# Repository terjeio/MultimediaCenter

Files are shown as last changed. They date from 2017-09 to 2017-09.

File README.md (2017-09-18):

# Multimedia center with DAB/FM radio

Features:

High quality (IMO) pre-amp board with I2C control of inputs and VCA based volume control.

5 line inputs, one may be fitted with an internal RIAA-preamp (phono, for moving magnet cartridges).
2 line outputs with old-style tape copy function and post listening possible.

Power amplifier on/off switching via inbuilt relay river.

KeyStone DAB/FM-module may be fitted.

Custom Raspberry PI power switch with PC-style startup/shutdown, may be controlled over I2C or from a front panel button.
Has "breakout" socket for internal USB HDD.

IR Remote Control - RC5 protocol: for input selection, volume control and UI controller navigation.

Main controller built around a Texas Instruments Tiva C MPU, custom UI library with support for KeyStone radio-module.

Raspberry PI for media playback (via Kodi), in my configuration audio is fed via HDMI to a TV and then to a DAC mounted inside the pre-amp cabinet.

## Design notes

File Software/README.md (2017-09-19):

# Power control daemon for Raspberry Pi 2 & 3

This daemon monitors and sets a pin for handling power to the Raspberry Pi "PC-style".
It is written in plain C and does direct GPIO reads/writes.

The PowerSwitch PCB/firmware handles the power relay and a on/off button & status LED.

A short button press initiates power-up or shutdown according to the current state. A long press (> 4s) when the Pi is in the running state forces a hard reset.

The solution can easily be adopted to other usage scenarioes, I have made use of it in my 3D-printer controller that runs OctoPrint.

Installation details and references can be found in the source code.

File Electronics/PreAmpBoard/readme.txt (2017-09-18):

MAYA Huracan PreAmp MK III Rev. A by

Terje Io
Io Engineering

Licensed under CERN OHL v.1.2 or later except the RIAA-circuitry which I believe is public domain.

The RIAA-circuitry was published by now defunct danish magazine High Fidelity way back in the 1980's.
I no longer have a copy of the issue(s) related to the design so I am not sure about any related copyright
but it surely is available for non-commercial use.

NOTE: Rev A has not yet been been verified as a working design.

Firmware will be released as a separate package under a different license after the design is verified.

A limited number of PCBs might or might not be made available for purchase at cost.

Files are in KiCad format.

2017-09-18

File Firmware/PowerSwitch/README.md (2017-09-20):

# PowerSwitch firmware

Firmware code is in a [separate project](https://github.com/terjeio/PowerSwitchFirmware/) since it seems to me Git does not allow cloning of subfolders in a project. Also, it is convenient to be able to import the code straight into TIs cloud based IDE for compilation and upload.

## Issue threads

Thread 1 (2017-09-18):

PA part

Claudio-Sjo, 2017-09-18:
Hi,
power amplifier is still empty.
Will you add this also?
Did you consider reusing "Superfast PA" design?

terjeio, 2017-09-18:
My current power amplifier is based on an ancient Motorola design with some hard to source components, I am not sure I want to publish that. There are many designs available on the internet so it should not be a problem finding one that can be used. When I run out of PCBs for the current design I migth try class D topology in combination with switch-mode PSU.

I have not heard about "Superfast PA" before and a quick internet search did not make me any wiser. Do you have a link?

Claudio-Sjo, 2017-09-18:
Hi,
superfast is AB class amplifier, some 300V/usec and 0.01% distorsion at full power on the entire bandwidth.
This is a scheme from the web
http://www.soton.ac.uk/~apm3/diyaudio/Stochino_circuit.jpg
I have the original design as published in Electronics World in the late 90s.

terjeio, 2017-09-19:
Thanks for the link, some interesting stuff there. I had a Wireless World collection going back some 30 years that I dumped a few years ago due to space restrictions - sometimes I regret doing that...

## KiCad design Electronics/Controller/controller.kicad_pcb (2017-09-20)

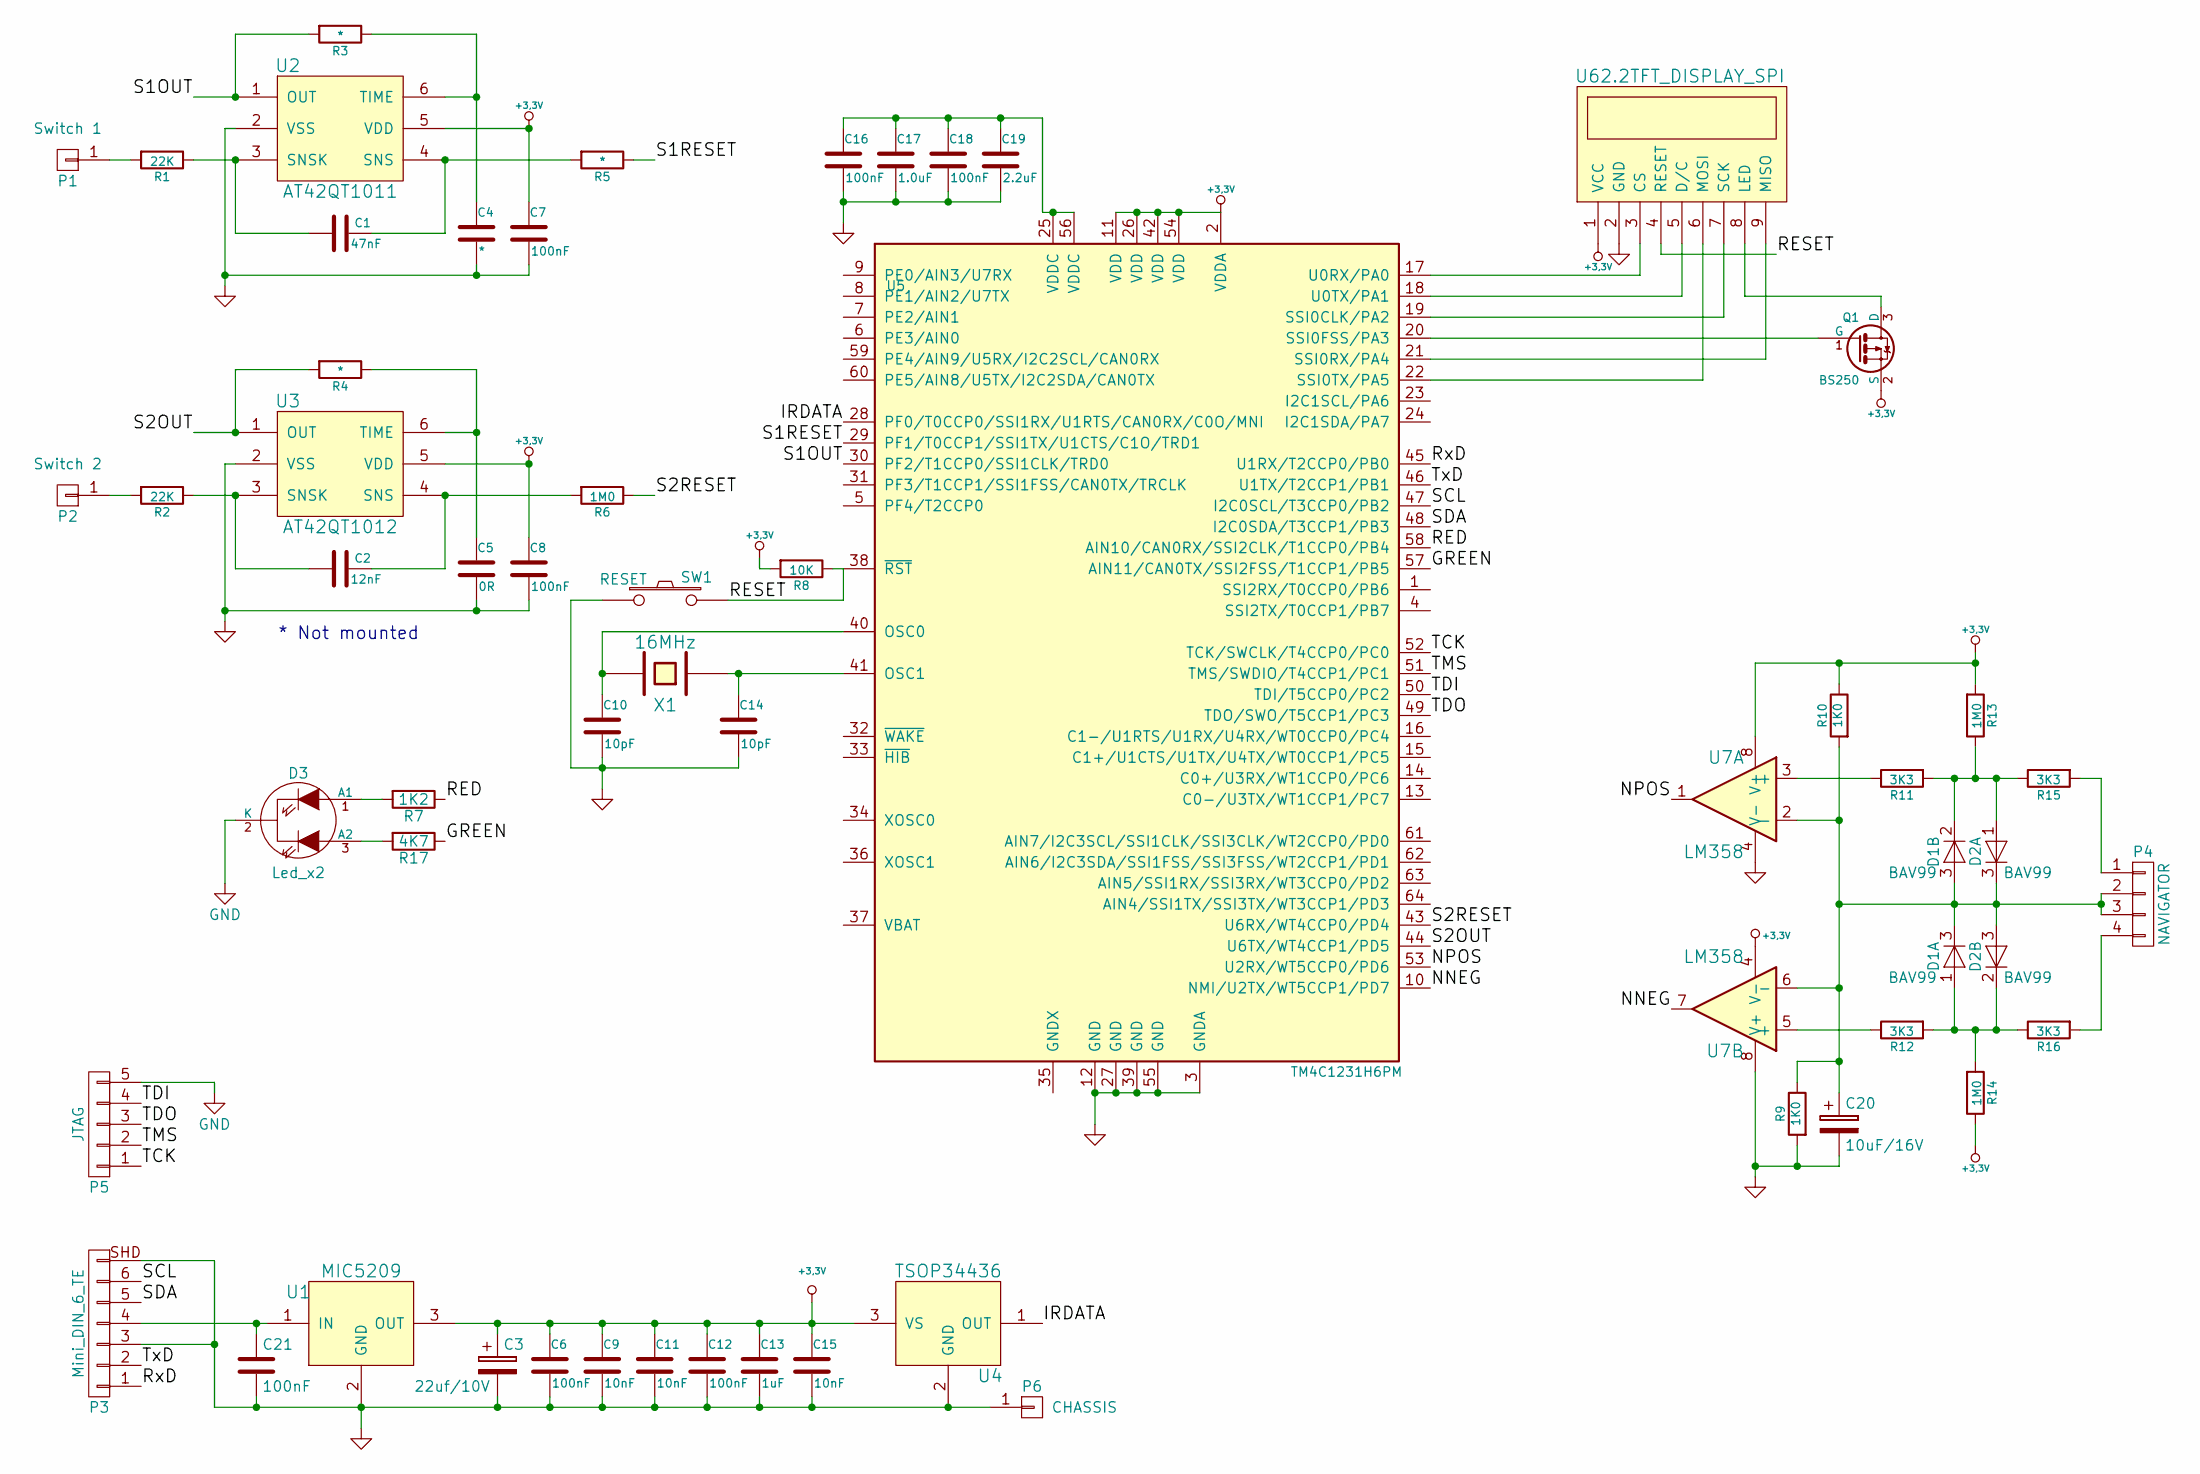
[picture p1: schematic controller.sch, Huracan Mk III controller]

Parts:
C1: 47nF; C_0805
C2: 12nF; C_0805
C3: 22uf/10V; TantalC_SizeA_EIA-3216_Reflow
C4: *; C_0805
C5: 0R; C_0805
C6, C7, C8, C12, C16, C18, C21: 100nF; C_0805
C9, C11, C15: 10nF; C_0805
C10, C14: 10pF; C_0805
C13: 1uF; C_0805
C17: 1.0uF; C_0805
C19: 2.2uF; C_1206
C20: 10uF/16V; TantalC_SizeA_EIA-3216_Reflow
D1, D2: BAV99; SOT-23
D3: Led_x2; LED-3MM-2
P1: Switch 1; Pin_Header_Straight_1x01
P2: Switch 2; Pin_Header_Straight_1x01
P3: Mini_DIN_6_TE; Mini_DIN_6_TE_Connectivity
P4: NAVIGATOR; Pin_Header_Straight_1x04
P5: JTAG; Pin_Header_Straight_1x05
P6: CHASSIS; Socket_Strip_Straight_1x01
Q1: BS250; SOT-23
R1, R2: 22K; R_1206
R3, R4, R5: *; R_1206
R6, R13, R14: 1M0; R_1206
R7: 1K2; R_1206
R8: 10K; R_1206
R9, R10: 1K0; R_1206
R11, R12, R15, R16: 3K3; R_1206
R17: 4K7; R_1206
SW1: RESET; SWITCH_TAC_H7.3
U1: MIC5209; SOT223
U2: AT42QT1011; SOT23-6
U3: AT42QT1012; SOT23-6
U4: TSOP34436; Pin_Header_Straight_1x03
U5: TM4C1231H6PM; LQFP-64_10x10mm_Pitch0.5mm
U6: 2.2TFT_DISPLAY_SPI; QVGA_2.2
U7: LM358; SO-8
X1: 16MHz; XTAL_ABM7_6x3.5MM

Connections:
/GREEN: R17.1, U5.57 (AIN11/CAN0TX/SSI2FSS/T1CCP1/PB5)
/IRDATA: U4.1 (OUT), U5.28 (PF0/T0CCP0/SSI1RX/U1RTS/CAN0RX/C0O/MNI)
/NNEG: U5.10 (NMI/U2TX/WT5CCP1/PD7), U7.7
/NPOS: U5.53 (U2RX/WT5CCP0/PD6), U7.1
/RED: R7.1, U5.58 (AIN10/CAN0RX/SSI2CLK/T1CCP0/PB4)
/RESET: R8.1, SW1.2, U5.38 (~RST~), U6.4 (RESET)
/RxD: P3.1, U5.45 (U1RX/T2CCP0/PB0)
/S1OUT: R3.2, U2.1 (OUT), U5.30 (PF2/T1CCP0/SSI1CLK/TRD0)
/S1RESET: R5.1, U5.29 (PF1/T0CCP1/SSI1TX/U1CTS/C1O/TRD1)
/S2OUT: R4.2, U3.1 (OUT), U5.44 (U6TX/WT4CCP1/PD5)
/S2RESET: R6.1, U5.43 (U6RX/WT4CCP0/PD4)
/SCL: P3.6, U5.47 (I2C0SCL/T3CCP0/PB2)
/SDA: P3.5, U5.48 (I2C0SDA/T3CCP1/PB3)
/TCK: P5.1, U5.52 (TCK/SWCLK/T4CCP0/PC0)
/TDI: P5.4, U5.50 (TDI/T5CCP0/PC2)
/TDO: P5.3, U5.49 (TDO/SWO/T5CCP1/PC3)
/TMS: P5.2, U5.51 (TMS/SWDIO/T4CCP1/PC1)
/TxD: P3.2, U5.46 (U1TX/T2CCP1/PB1)
unnamed: C1.1, R1.1, U2.3 (SNSK)
unnamed: C1.2, R5.2, U2.4 (SNS)
unnamed: C2.1, R2.1, U3.3 (SNSK)
unnamed: C2.2, R6.2, U3.4 (SNS)
unnamed: C4.1, R3.1, U2.6 (TIME)
unnamed: C5.1, R4.1, U3.6 (TIME)
unnamed: C10.1, U5.40 (OSC0), X1.2
unnamed: C14.1, U5.41 (OSC1), X1.1
unnamed: C16.1, C17.1, C18.1, C19.1, U5.25 (VDDC), U5.56 (VDDC)
unnamed: C20.1, D1.3 (K), D2.3 (K), P4.2, P4.3, R9.1, R10.2, U7.2 (-), U7.6 (-)
unnamed: C21.1, P3.4, U1.1 (IN)
unnamed: D1.1 (A), D2.2 (K), R12.2, R14.2, R16.1
unnamed: D1.2 (K), D2.1 (A), R11.2, R13.1, R15.1
unnamed: D3.1 (A1), R7.2
unnamed: D3.3 (A2), R17.2
unnamed: P1.1, R1.2
unnamed: P2.1, R2.2
unnamed: P4.1, R15.2
unnamed: P4.4, R16.2
unnamed: Q1.1 (G), U5.20 (SSI0FSS/PA3)
unnamed: Q1.3 (D), U6.8 (LED)
unnamed: R11.1, U7.3 (+)
unnamed: R12.1, U7.5 (+)
unnamed: U5.17 (U0RX/PA0), U6.3 (CS)
unnamed: U5.18 (U0TX/PA1), U6.5 (D/C)
unnamed: U5.19 (SSI0CLK/PA2), U6.7 (SCK)
unnamed: U5.21 (SSI0RX/PA4), U6.9 (MISO)
unnamed: U5.22 (SSI0TX/PA5), U6.6 (MOSI)

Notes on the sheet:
* Not mounted

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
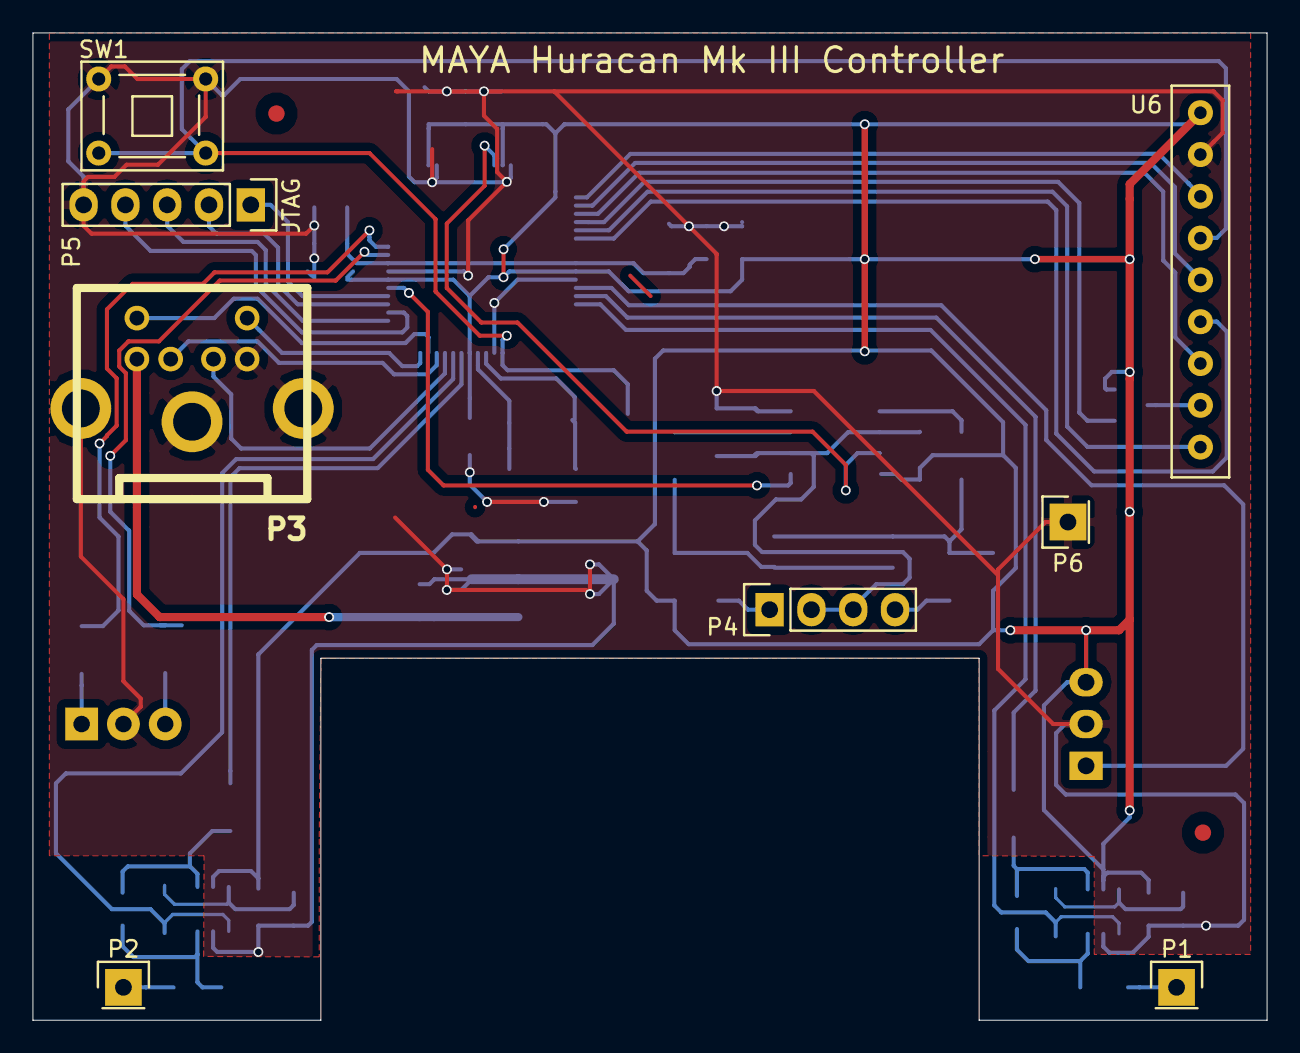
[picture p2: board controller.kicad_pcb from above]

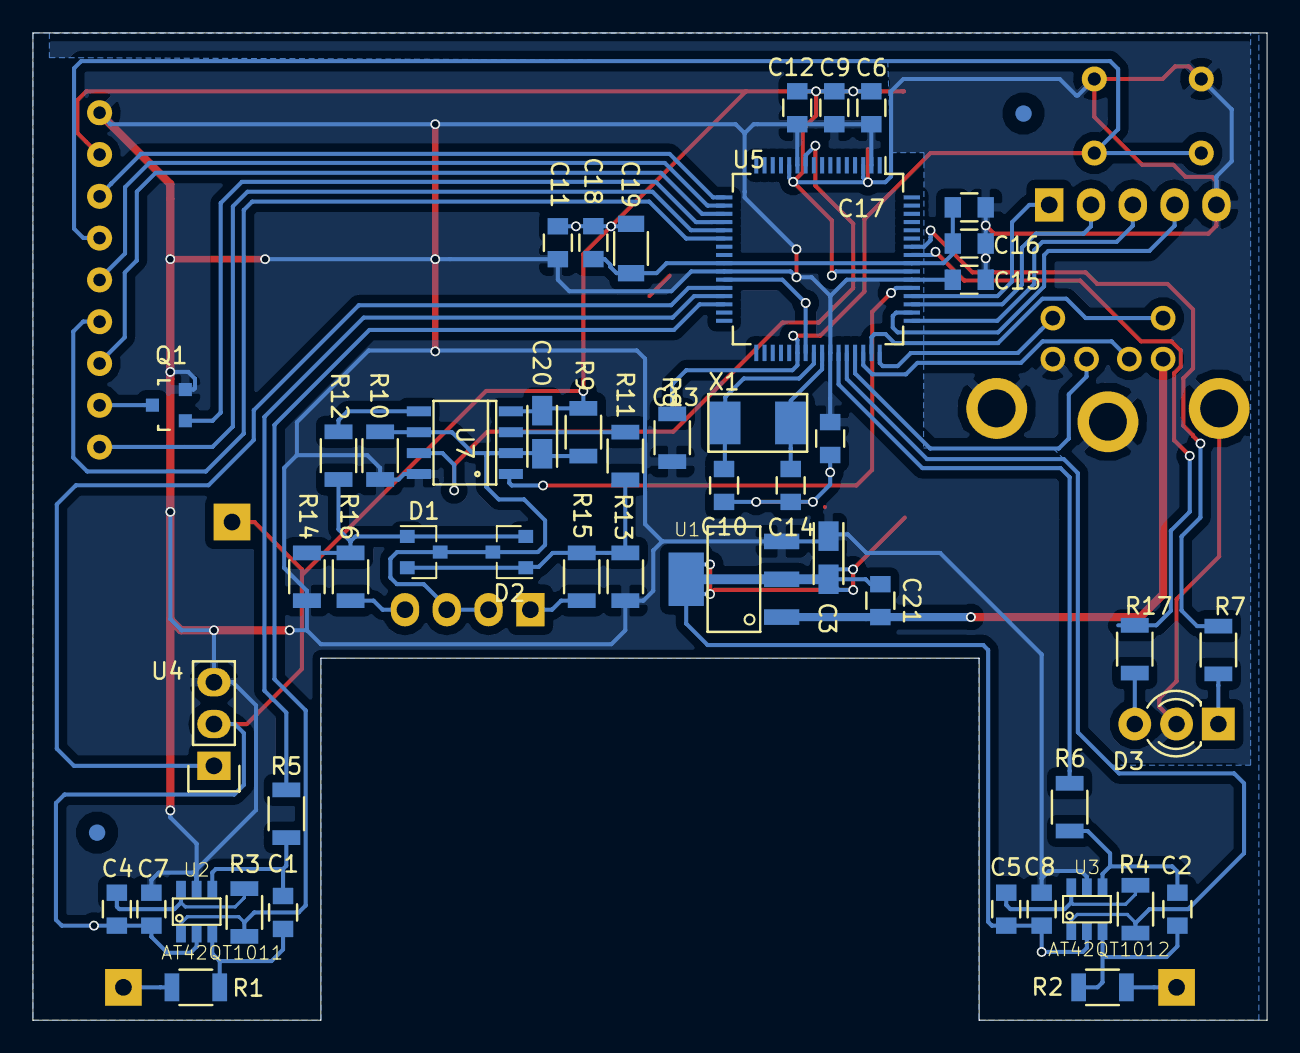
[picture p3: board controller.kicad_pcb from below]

Board: 2 copper layers, 75.0 x 60.0 mm, 57 parts (49 on the bottom side), 48 nets.

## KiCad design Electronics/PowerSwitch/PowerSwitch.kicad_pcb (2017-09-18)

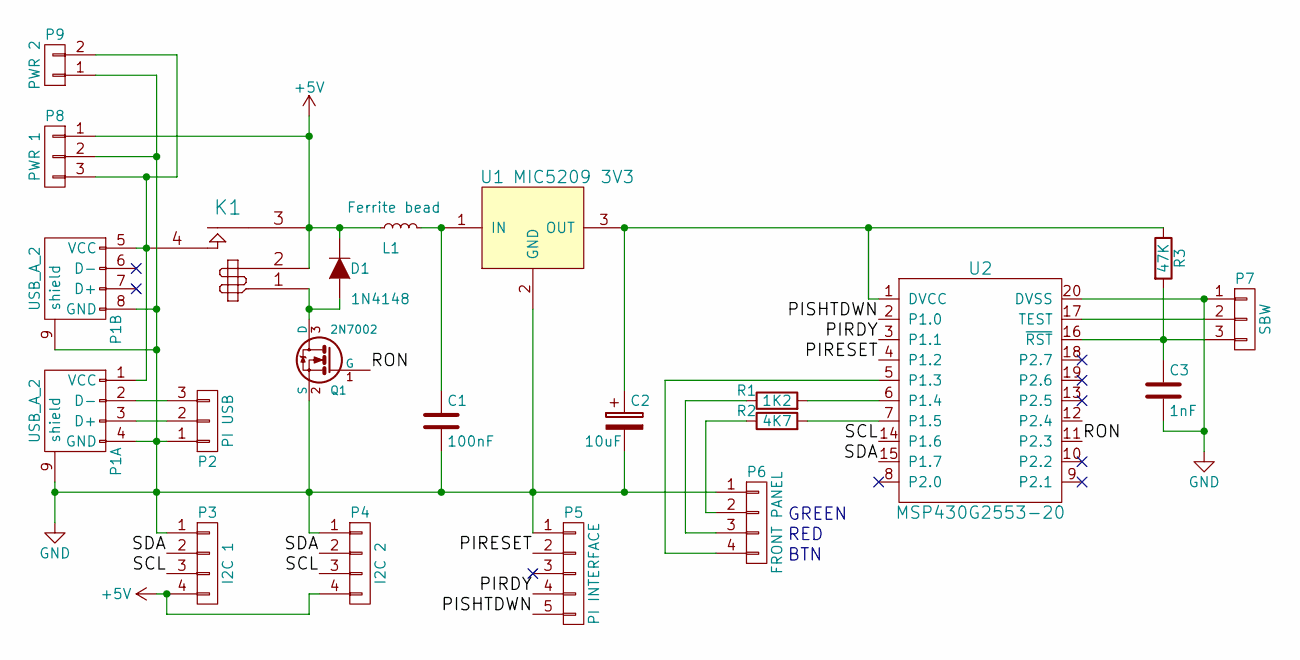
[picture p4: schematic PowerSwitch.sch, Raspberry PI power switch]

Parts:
C1: 100nF; C_1206
C2: 10uF; TantalC_SizeA_EIA-3216_Reflow
C3: 1nF; C_1206
D1: 1N4148; SOD-123
K1: RELAY-LD-P; PANASONIC_LD_P_RELAY
L1: Ferrite bead; Resistor_Horizontal_RM10mm
P1: USB_A_2
P2: PI USB; Pin_Header_Straight_1x03
P3: I2C 1; Pin_Header_Straight_1x04
P4: I2C 2; Pin_Header_Straight_1x04
P5: PI INTERFACE; Pin_Header_Straight_1x05
P6: FRONT PANEL; Pin_Header_Straight_1x04
P7: SBW; Pin_Header_Straight_1x03
P8: PWR 1; CONN_PWR_3P
P9: PWR 2; Pin_Header_Straight_1x02
Q1: 2N7002; SOT-23
R1: 1K2; R_1206
R2: 4K7; R_1206
R3: 47K; R_1206
U1: MIC5209 3V3; AB2_SOT223
U2: MSP430G2553-20; TSSOP20

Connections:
+5V: D1.1 (K), K1.2, K1.3, L1.1, P3.4, P4.4, P8.1
/PIRDY: P5.4, U2.3 (P1.1)
/PIRESET: P5.2, U2.4 (P1.2)
/PISHTDWN: P5.5, U2.2 (P1.0)
/RON: Q1.1 (G), U2.11 (P2.3)
/SCL: P3.3, P4.3, U2.14 (P1.6)
/SDA: P3.2, P4.2, U2.15 (P1.7)
GND: C1.2, C2.2, C3.2, P1.4 (GND), P1.8 (GND), P1.9 (shield), P2.1, P3.1, P4.1, P5.1, P6.1, P7.1, P8.2, P9.1, Q1.2 (S), U1.2 (GND), U2.20 (DVSS)
unnamed: C1.1, L1.2, U1.1 (IN)
unnamed: C2.1, R3.1, U1.3 (OUT), U2.1 (DVCC)
unnamed: C3.1, P7.3, R3.2, U2.16 (~RST~)
unnamed: D1.2 (A), K1.1, Q1.3 (D)
unnamed: K1.4, P1.1 (VCC), P1.5 (VCC), P8.3, P9.2
unnamed: P1.2 (D-), P2.3
unnamed: P1.3 (D+), P2.2
unnamed: P6.2, R2.1
unnamed: P6.3, R1.1
unnamed: P6.4, U2.5 (P1.3)
unnamed: P7.2, U2.17 (TEST)
unnamed: R1.2, U2.6 (P1.4)
unnamed: R2.2, U2.7 (P1.5)

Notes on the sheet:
RED
GREEN
BTN

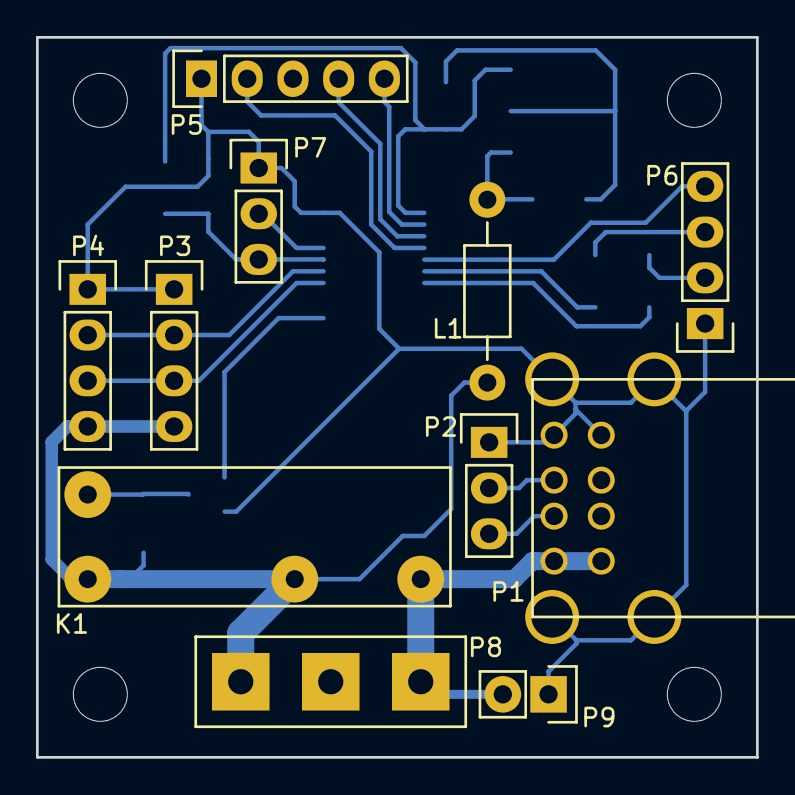
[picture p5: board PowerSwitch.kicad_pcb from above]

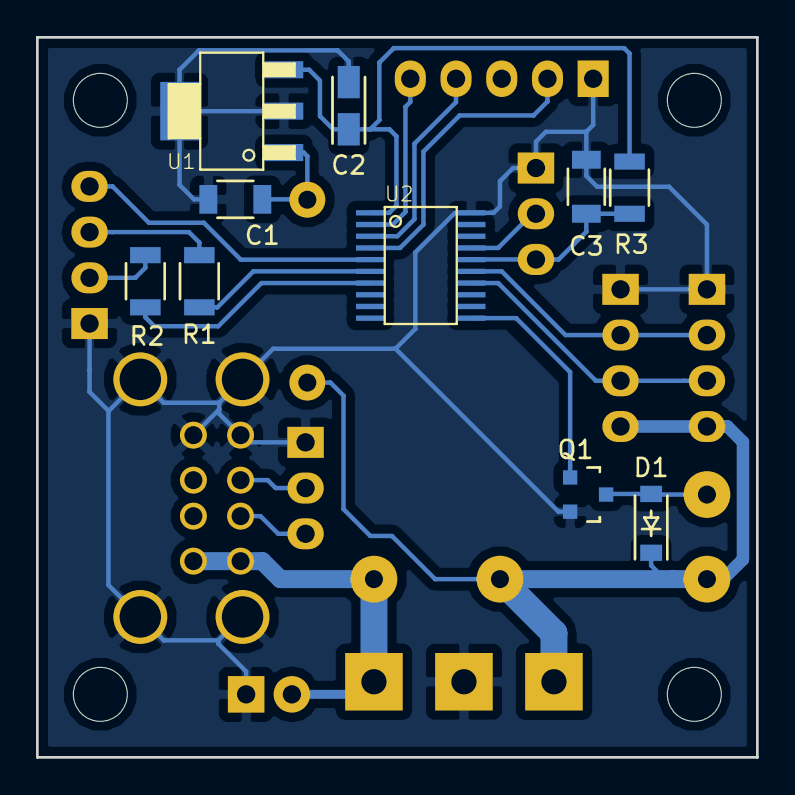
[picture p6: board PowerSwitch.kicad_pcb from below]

Board: 2 copper layers, 40.0 x 40.0 mm, 21 parts (10 on the bottom side), 21 nets.

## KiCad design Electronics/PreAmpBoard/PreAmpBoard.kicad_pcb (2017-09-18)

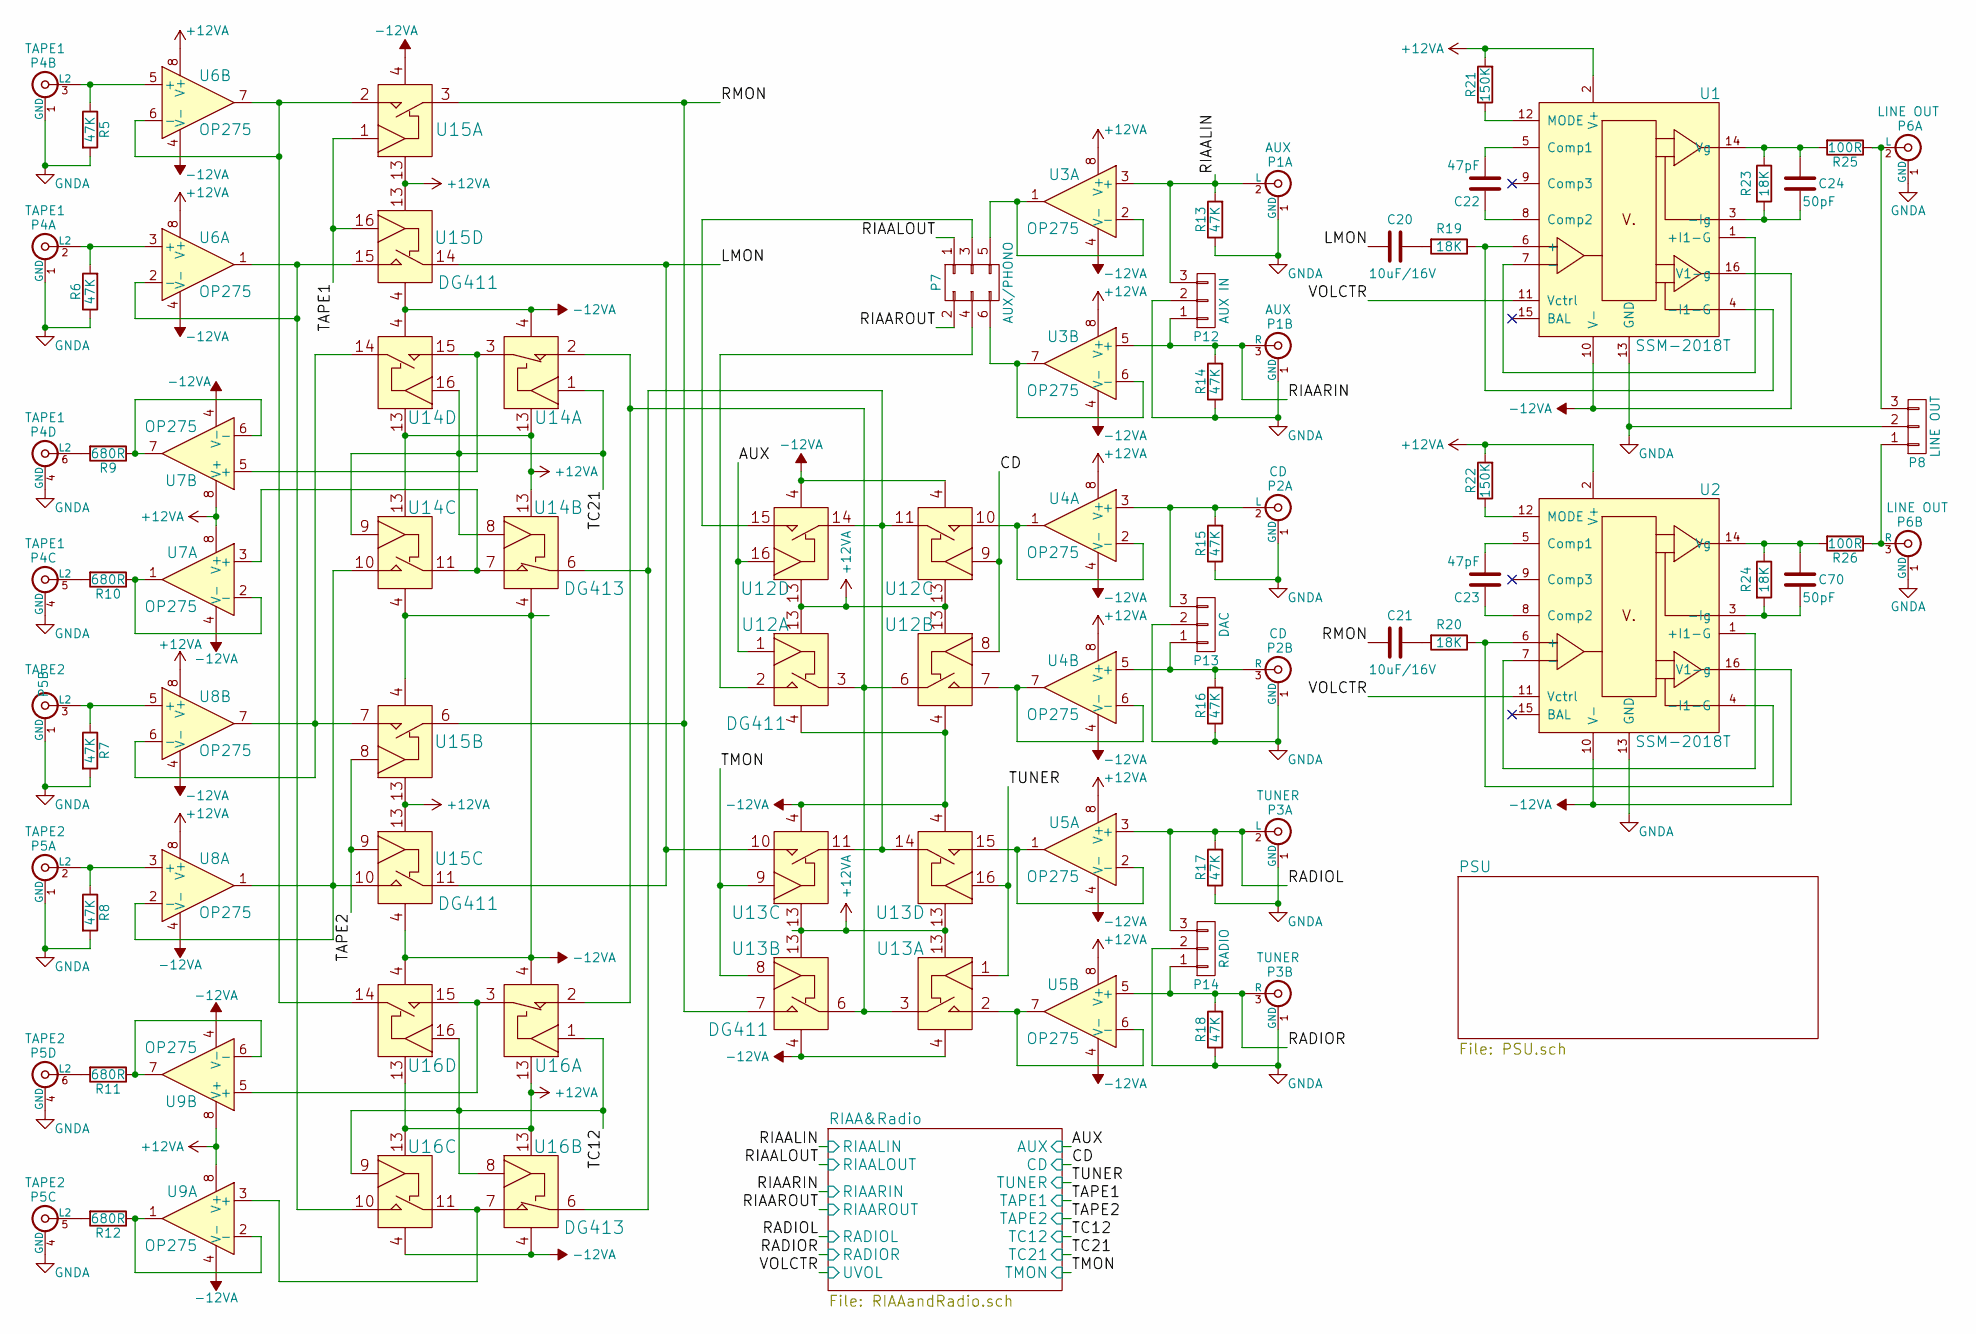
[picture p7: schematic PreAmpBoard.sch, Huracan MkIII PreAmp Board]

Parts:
C20, C21: 10uF/16V; C_Radial_D5_L11_P2.5
C22, C23: 47pF; C_Disc_D3_P5
C24, C70: 50pF; C_Disc_D3_P5
P1: AUX; PSG01550
P2: CD; PSG01550
P3: TUNER; PSG01550
P4: TAPE1; PSG01551
P5: TAPE2; PSG01551
P6: LINE OUT; PSG01550
P7: AUX/PHONO; Pin_Header_Straight_2x03
P8: LINE OUT; 70543-03
P12: AUX IN; 70543-03
P13: DAC; 70543-03
P14: RADIO; 70543-03
R5, R6, R7, R8, R13, R14, R15, R16, R17, R18: 47K; Resistor_Horizontal_RM10mm
R9, R10, R11, R12: 680R; Resistor_Horizontal_RM10mm
R19, R20, R23, R24: 18K; Resistor_Horizontal_RM10mm
R21, R22: 150K; Resistor_Horizontal_RM10mm
R25, R26: 100R; Resistor_Horizontal_RM10mm
U1, U2: SSM-2018T; SOIC-16_7.5x10.3mm_Pitch1.27mm
U3, U4, U5, U6, U7, U8, U9: OP275; DIP-8__300
U12, U13, U15: DG411; SOIC-16_3.9x9.9mm_Pitch1.27mm
U14, U16: DG413; SOIC-16_3.9x9.9mm_Pitch1.27mm

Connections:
+12VA: R21.2, R22.2, U1.2 (V+), U2.2 (V+), U3.8 (V+), U4.8 (V+), U5.8 (V+), U6.8 (V+), U7.8 (V+), U8.8 (V+), U9.8 (V+), U12.13 (V+), U13.13 (V+), U14.13 (V+), U15.13 (V+), U16.13 (V+); also elsewhere on the board
/AUX: U12.1 (SW), U12.16 (SW); also elsewhere on the board
/CD: U12.8 (SW), U12.9 (SW); also elsewhere on the board
/LMON: C20.2, U13.10 (IN), U15.11 (OUT), U15.14 (OUT)
/RADIOL: P3.2 (L), P14.3, R17.2, U5.3 (+); also elsewhere on the board
/RADIOR: P3.3 (R), P14.1, R18.2, U5.5 (+); also elsewhere on the board
/RIAALIN: P1.2 (L), P12.3, R13.2, U3.3 (+); also elsewhere on the board
/RIAALOUT: P7.1; also elsewhere on the board
/RIAARIN: P1.3 (R), P12.1, R14.2, U3.5 (+); also elsewhere on the board
/RIAAROUT: P7.2; also elsewhere on the board
/RMON: C21.2, U13.7 (IN), U15.3 (OUT), U15.6 (OUT)
/TAPE1: U15.1 (SW), U15.16 (SW); also elsewhere on the board
/TAPE2: U15.8 (SW), U15.9 (SW); also elsewhere on the board
/TC12: U16.1 (SW), U16.8 (SW), U16.9 (SW), U16.16 (SW); also elsewhere on the board
/TC21: U14.1 (SW), U14.8 (SW), U14.9 (SW), U14.16 (SW); also elsewhere on the board
/TMON: U13.8 (SW), U13.9 (SW); also elsewhere on the board
/TUNER: U13.1 (SW), U13.16 (SW); also elsewhere on the board
/VOLCTR: U1.11 (Vctrl), U2.11 (Vctrl); also elsewhere on the board
GND: P1.1 (GND), P2.1 (GND), P3.1 (GND), P4.1 (GND), P4.4 (GND), P5.1 (GND), P5.4 (GND), P6.1 (GND), P8.2, P12.2, P13.2, P14.2, R5.2, R6.1, R7.2, R8.2, R13.1, R14.1, R15.1, R16.1, R17.1, R18.1, U1.13 (GND), U2.13 (GND), U12.5 (GND), U13.5 (GND), U14.5 (GND), U15.5 (GND), U16.5 (GND); also elsewhere on the board
unnamed: C20.1, R19.2
unnamed: C21.1, R20.2
unnamed: C22.1, U1.8 (Comp2)
unnamed: C22.2, U1.5 (Comp1)
unnamed: C23.1, U2.8 (Comp2)
unnamed: C23.2, U2.5 (Comp1)
unnamed: C24.1, R23.2, U1.3 (-Ig)
unnamed: C24.2, R23.1, R25.2, U1.14 (Vg)
unnamed: C70.1, R24.2, U2.3 (-Ig)
unnamed: C70.2, R24.1, R26.2, U2.14 (Vg)
unnamed: P4.2 (L2), R6.2, U6.3 (+)
unnamed: P4.3 (L2), R5.1, U6.5 (+)
unnamed: P4.5 (L2), R10.2
unnamed: P4.6 (L2), R9.2
unnamed: P5.2 (L2), R8.1, U8.3 (+)
unnamed: P5.3 (L2), R7.1, U8.5 (+)
unnamed: P5.5 (L2), R12.2
unnamed: P5.6 (L2), R11.2
unnamed: P6.2 (L), P8.3, R25.1
unnamed: P6.3 (R), P8.1, R26.1
unnamed: P7.3, U12.15 (IN)
unnamed: P7.4, U12.2 (IN)
unnamed: P2.3 (R), P13.1, R16.2, U4.5 (+)
unnamed: P2.2 (L), P13.3, R15.2, U4.3 (+)
unnamed: R19.1, U1.4 (-I1-G), U1.6 (+)
unnamed: R20.1, U2.4 (-I1-G), U2.6 (+)
unnamed: R21.1, U1.12 (MODE)
unnamed: R22.1, U2.12 (MODE)
unnamed: U1.1 (+I1-G), U1.7 (-)
unnamed: U2.1 (+I1-G), U2.7 (-)
unnamed: U12.3 (OUT), U12.6 (OUT), U13.3 (OUT), U13.6 (OUT), U14.2 (IN), U16.2 (IN)
unnamed: U12.11 (OUT), U12.14 (OUT), U13.11 (OUT), U13.14 (OUT), U14.6 (OUT), U16.6 (OUT)
unnamed: U7.3 (+), U14.7 (IN), U14.11 (OUT)
unnamed: U7.5 (+), U14.3 (OUT), U14.15 (IN)
unnamed: U9.3 (+), U16.7 (IN), U16.11 (OUT)
unnamed: U9.5 (+), U16.3 (OUT), U16.15 (IN)
VCC: U12.12 (VCC), U13.12 (VCC), U14.12 (VCC), U15.12 (VCC), U16.12 (VCC); also elsewhere on the board

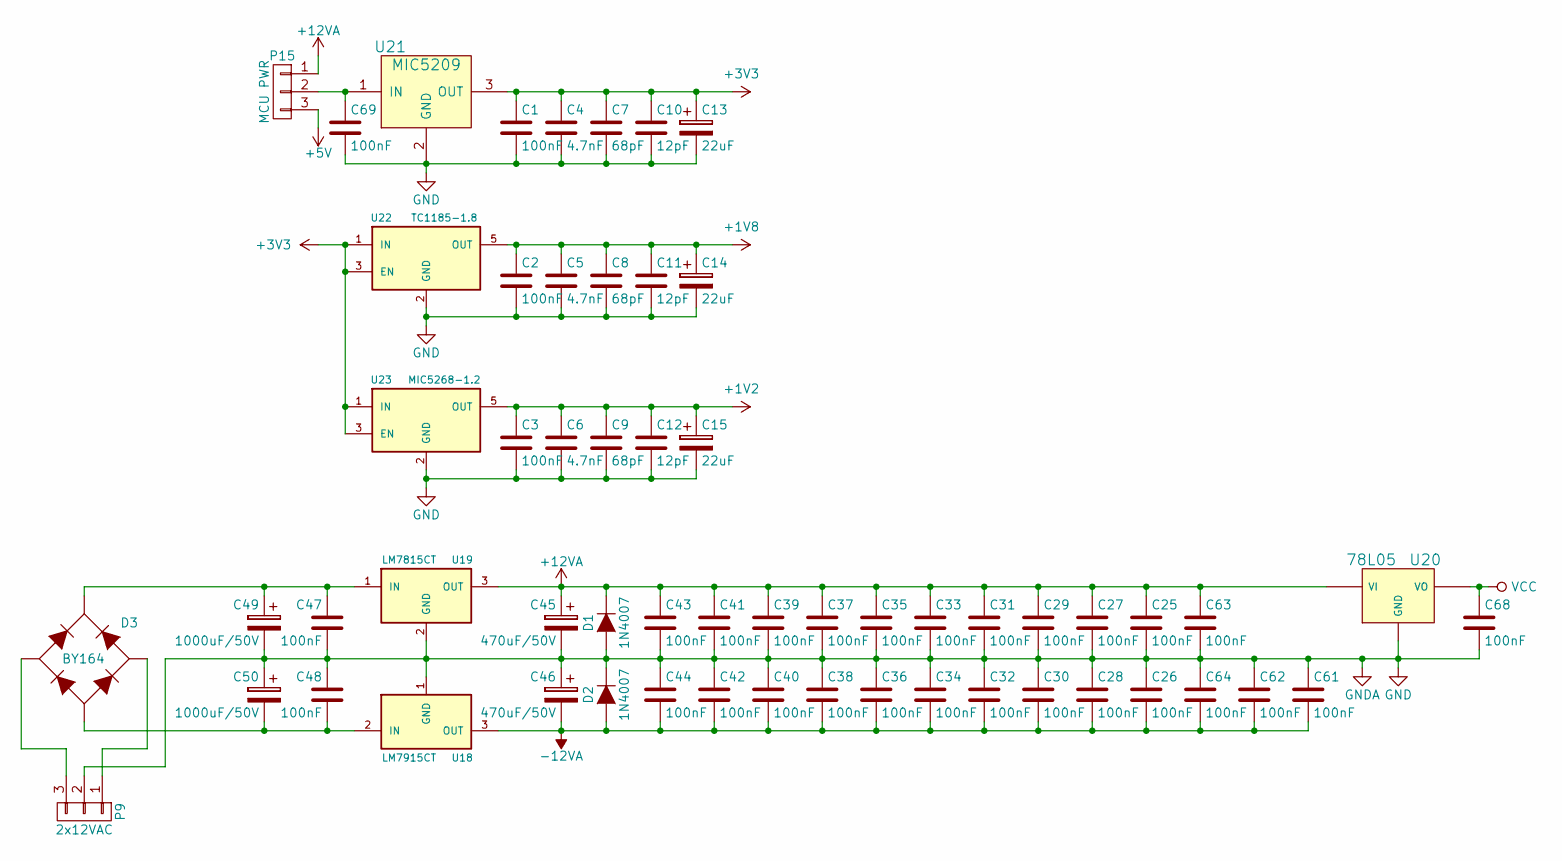
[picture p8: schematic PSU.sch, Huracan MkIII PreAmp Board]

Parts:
C1, C2, C3, C68, C69: 100nF; C_1206
C4, C5, C6: 4.7nF; C_0805
C7, C8, C9: 68pF; C_0805
C10, C11, C12: 12pF; C_0805
C13, C14, C15: 22uF; TantalC_SizeA_EIA-3216_Reflow
C25, C26, C27, C28, C29, C30, C31, C32, C33, C34, C35, C36, C37, C38, C39, C40, C41, C42, C43, C44, C47, C48, C61, C62, C63, C64: 100nF; C_Disc_D3_P5
C45, C46: 470uF/50V; C_Radial_D10_L20_P5
C49, C50: 1000uF/50V; C_Radial_D16_L25_P7.5
D1, D2: 1N4007; Diode_DO-41_SOD81_Horizontal_RM10
D3: BY164; BRIDGE_RECTIFIER_5MM
P9: 2x12VAC; CONN_PWR_3P
P15: MCU PWR; Pin_Header_Straight_1x03
U18: LM7915CT; TO-220-10x15VFIN
U19: LM7815CT; TO-220-10x15VFIN
U20: 78L05; TO-92_Inline_Narrow_Oval
U21: MIC5209; SOT223
U22: TC1185-1.8; SOT-23-5
U23: MIC5268-1.2; SOT-23-5

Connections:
+1V2: C3.1, C6.1, C9.1, C12.1, C15.1, U23.5 (OUT); also elsewhere on the board
+1V8: C2.1, C5.1, C8.1, C11.1, C14.1, U22.5 (OUT); also elsewhere on the board
+3V3: C1.1, C4.1, C7.1, C10.1, C13.1, U21.3 (OUT), U22.1 (IN), U22.3 (EN), U23.1 (IN), U23.3 (EN); also elsewhere on the board
+5V: P15.3
+12VA: C25.1, C27.1, C29.1, C31.1, C33.1, C35.1, C37.1, C39.1, C41.1, C43.1, C45.1, C63.1, D1.1 (K), P15.1, U19.3 (OUT), U20.3 (VI); also elsewhere on the board
GND: C1.2, C2.2, C3.2, C4.2, C5.2, C6.2, C7.2, C8.2, C9.2, C10.2, C11.2, C12.2, C13.2, C14.2, C15.2, C25.2, C26.1, C27.2, C28.1, C29.2, C30.1, C31.2, C32.1, C33.2, C34.1, C35.2, C36.1, C37.2, C38.1, C39.2, C40.1, C41.2, C42.1, C43.2, C44.1, C45.2, C46.1, C47.2, C48.1, C49.2, C50.1, C61.1, C62.1, C63.2, C64.1, C68.2, C69.2, D1.2 (A), D2.1 (K), P9.2, U18.1 (GND), U19.2 (GND), U20.2 (GND), U21.2 (GND), U22.2 (GND), U23.2 (GND); also elsewhere on the board
unnamed: C47.1, C49.1, D3.4 (+), U19.1 (IN)
unnamed: C48.2, C50.2, D3.1 (-), U18.2 (IN)
unnamed: C69.1, P15.2, U21.1 (IN)
unnamed: D3.2 (AC), P9.3
unnamed: D3.3 (AC), P9.1
VCC: C68.1, U20.1 (VO); also elsewhere on the board

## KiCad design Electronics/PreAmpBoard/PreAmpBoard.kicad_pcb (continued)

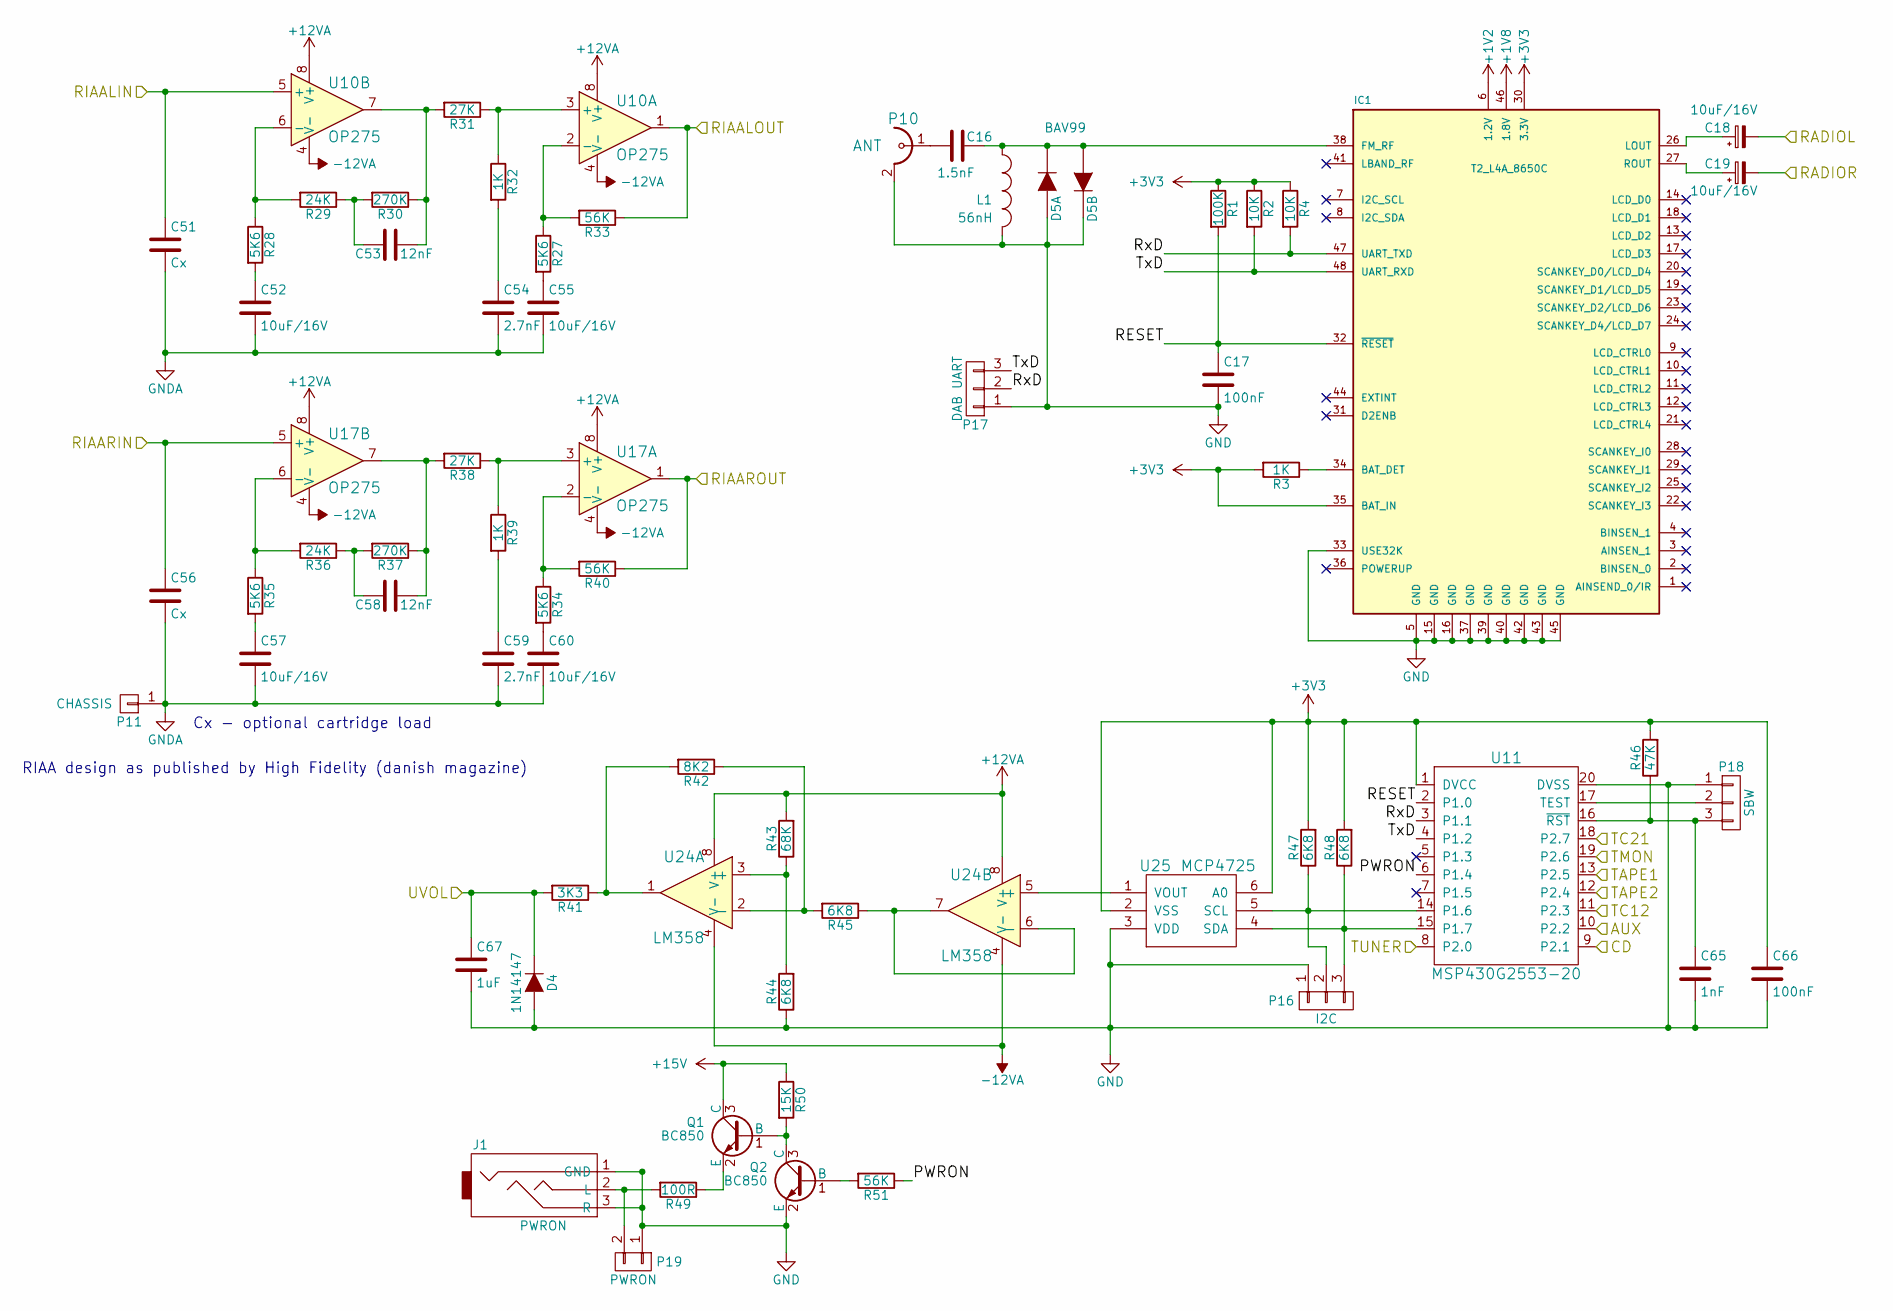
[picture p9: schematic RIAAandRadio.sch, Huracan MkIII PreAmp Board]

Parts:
C16: 1.5nF; C_0805
C17, C66: 100nF; C_1206
C18, C19: 10uF/16V; c_elec_3x5.3
C51, C56: Cx; C_Disc_D3_P5
C52, C55, C57, C60: 10uF/16V; C_Radial_D5_L11_P2.5
C53, C58: 12nF; C_Disc_D3_P5
C54, C59: 2.7nF; C_Disc_D3_P5
C65: 1nF; C_0805
C67: 1uF; C_1206
D4: 1N14147; SOD-123
D5: BAV99; SOT-23
IC1: T2_L4A_8650C; T2-L4A-8650C
J1: PWRON; PSG01538
L1: 56nH; R_0805
P10: ANT; CON-SMA-EDGE
P11: CHASSIS; Pin_Header_Straight_1x01
P16: I2C; 70543-03
P17: DAB UART; 70543-03
P18: SBW; Pin_Header_Straight_1x03
P19: PWRON; Pin_Header_Straight_1x02
Q1, Q2: BC850; SOT-23
R1: 100K; R_0805
R2, R4: 10K; R_0805
R3: 1K; R_0805
R27, R28, R34, R35: 5K6; Resistor_Horizontal_RM10mm
R29, R36: 24K; Resistor_Horizontal_RM10mm
R30, R37: 270K; Resistor_Horizontal_RM10mm
R31, R38: 27K; Resistor_Horizontal_RM10mm
R32, R39: 1K; Resistor_Horizontal_RM10mm
R33, R40: 56K; Resistor_Horizontal_RM10mm
R41: 3K3; R_0805
R42: 8K2; R_0805
R43: 68K; R_0805
R44, R45, R47, R48: 6K8; R_0805
R46: 47K; R_0805
R49: 100R; Resistor_Horizontal_RM10mm
R50: 15K; R_0805
R51: 56K; R_0805
U10, U17: OP275; DIP-8__300
U11: MSP430G2553-20; TSSOP20
U24: LM358; SO-8
U25: MCP4725; SOT23-6

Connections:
+1V2: IC1.6 (1.2V); also elsewhere on the board
+1V8: IC1.46 (1.8V); also elsewhere on the board
+3V3: C66.1, IC1.30 (3.3V), IC1.35 (BAT_IN), R1.1, R2.1, R3.2, R4.1, R46.2, R47.2, R48.2, U11.1 (DVCC), U25.2 (VSS), U25.6 (A0); also elsewhere on the board
+12VA: R43.2, U10.8 (V+), U17.8 (V+), U24.8 (V+); also elsewhere on the board
+15V: Q1.3 (C), R50.1
/AUX: U11.10 (P2.2); also elsewhere on the board
/CD: U11.9 (P2.1); also elsewhere on the board
/RADIOL: C18.2; also elsewhere on the board
/RADIOR: C19.2; also elsewhere on the board
/RIAA&Radio/PWRON: R51.1, U11.6 (P1.4)
/RIAA&Radio/RESET: C17.1, IC1.32 (~RESET), R1.2, U11.2 (P1.0)
/RIAA&Radio/RxD: IC1.47 (UART_TXD), P17.2, R4.2, U11.3 (P1.1)
/RIAA&Radio/TxD: IC1.48 (UART_RXD), P17.3, R2.2, U11.4 (P1.2)
/RIAALIN: C51.1, U10.5 (+); also elsewhere on the board
/RIAALOUT: R33.1, U10.1; also elsewhere on the board
/RIAARIN: C56.1, U17.5 (+); also elsewhere on the board
/RIAAROUT: R40.1, U17.1; also elsewhere on the board
/TAPE1: U11.13 (P2.5); also elsewhere on the board
/TAPE2: U11.12 (P2.4); also elsewhere on the board
/TC12: U11.11 (P2.3); also elsewhere on the board
/TC21: U11.18 (P2.7); also elsewhere on the board
/TMON: U11.19 (P2.6); also elsewhere on the board
/TUNER: U11.8 (P2.0); also elsewhere on the board
/VOLCTR: C67.1, D4.1 (K), R41.2; also elsewhere on the board
GND: C17.2, C51.2, C52.2, C54.2, C55.2, C56.2, C57.2, C59.2, C60.2, C65.2, C66.2, C67.2, D4.2 (A), D5.1 (A), D5.2 (K), IC1.5 (GND), IC1.15 (GND), IC1.16 (GND), IC1.33 (USE32K), IC1.37 (GND), IC1.39 (GND), IC1.40 (GND), IC1.42 (GND), IC1.43 (GND), IC1.45 (GND), J1.1 (GND), J1.3 (R), L1.2, P10.2, P11.1, P16.1, P17.1, P18.1, P19.1, Q2.2 (E), R44.1, U11.20 (DVSS), U25.3 (VDD); also elsewhere on the board
unnamed: C16.1, P10.1
unnamed: C16.2, D5.3 (K), IC1.38 (FM_RF), L1.1
unnamed: C18.1, IC1.26 (LOUT)
unnamed: C19.1, IC1.27 (ROUT)
unnamed: C52.1, R28.2
unnamed: C53.1, R30.1, R31.2, U10.7
unnamed: C53.2, R29.1, R30.2
unnamed: C54.1, R32.2
unnamed: C55.1, R27.2
unnamed: C57.1, R35.2
unnamed: C58.1, R37.1, R38.2, U17.7
unnamed: C58.2, R36.1, R37.2
unnamed: C59.1, R39.2
unnamed: C60.1, R34.2
unnamed: C65.1, P18.3, R46.1, U11.16 (~RST~)
unnamed: IC1.34 (BAT_DET), R3.1
unnamed: J1.2 (L), P19.2, R49.2
unnamed: P16.2, R47.1, U11.14 (P1.6), U25.5 (SCL)
unnamed: P16.3, R48.1, U11.15 (P1.7), U25.4 (SDA)
unnamed: P18.2, U11.17 (TEST)
unnamed: Q1.1 (B), Q2.3 (C), R50.2
unnamed: Q1.2 (E), R49.1
unnamed: Q2.1 (B), R51.2
unnamed: R27.1, R33.2, U10.2 (-)
unnamed: R28.1, R29.2, U10.6 (-)
unnamed: R31.1, R32.1, U10.3 (+)
unnamed: R34.1, R40.2, U17.2 (-)
unnamed: R35.1, R36.2, U17.6 (-)
unnamed: R38.1, R39.1, U17.3 (+)
unnamed: R41.1, R42.2, U24.1
unnamed: R42.1, R45.2, U24.2 (-)
unnamed: R43.1, R44.2, U24.3 (+)
unnamed: R45.1, U24.6 (-), U24.7
unnamed: U24.5 (+), U25.1 (VOUT)

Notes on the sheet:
Cx - optional cartridge load
RIAA design as published by High Fidelity (danish magazine)

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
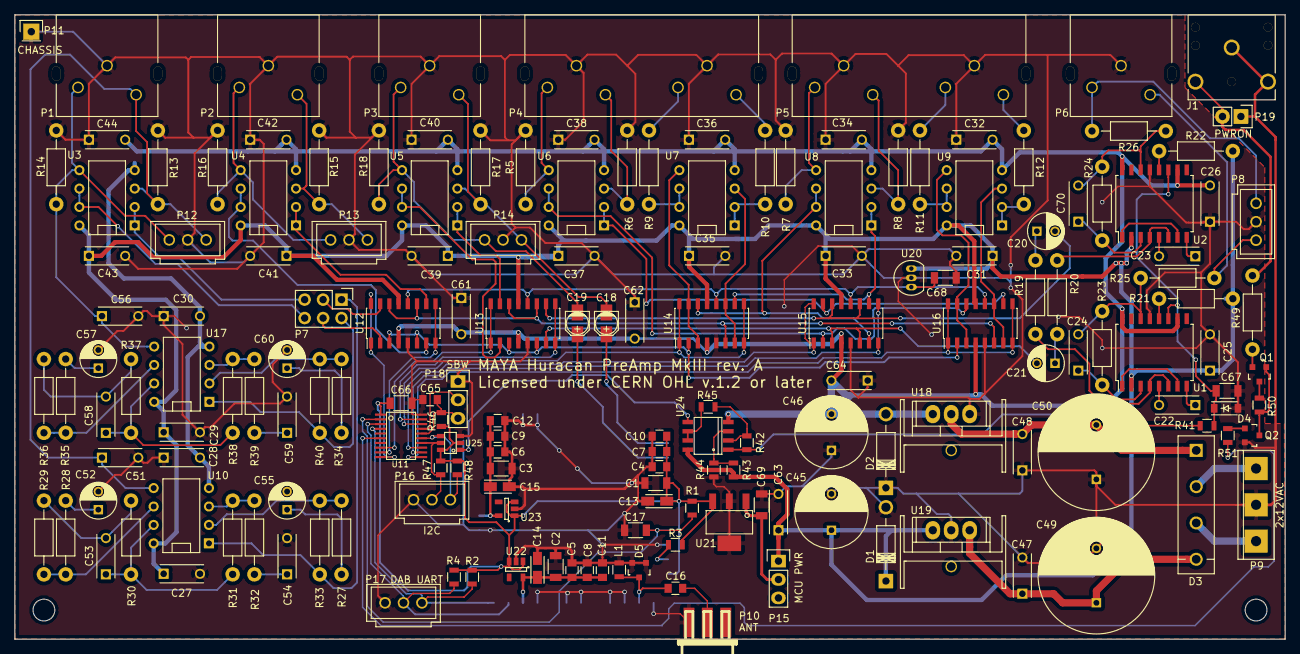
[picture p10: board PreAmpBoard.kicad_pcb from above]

Board: 2 copper layers, 175.0 x 86.0 mm, 175 parts (1 on the bottom side), 118 nets.

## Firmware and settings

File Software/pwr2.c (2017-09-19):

//
// pwr2.c - Huracan Pre Amp MK III Power switch for Raspberry Pi 2
//
// for Raspberry Pi 2 running OSMC
//
// v1.0 / 2015-04-15 / Io Engineering / Terje
//
// See http://www.linuxprofilm.com/articles/linux-daemon-howto.html
// for how to write a daemon
//
// See https://discourse.osmc.tv/t/install-custom-services-with-systemd-on-the-raspberry-2-using-osmc/3037
// for how to install a custom service
//

/*

Copyright (c) 2015, Terje Io
All rights reserved.

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
· Redistributions of source code must retain the above copyright notice, this
list of conditions and the following disclaimer.

· Redistributions in binary form must reproduce the above copyright notice, this
list of conditions and the following disclaimer in the documentation and/or
other materials provided with the distribution.

· Neither the name of the copyright holder nor the names of its contributors may
be used to endorse or promote products derived from this software without
specific prior written permission.

THIS SOFTWARE IS PROVIDED BY THE COPYRIGHT HOLDERS AND CONTRIBUTORS "AS IS" AND
ANY EXPRESS OR IMPLIED WARRANTIES, INCLUDING, BUT NOT LIMITED TO, THE IMPLIED
WARRANTIES OF MERCHANTABILITY AND FITNESS FOR A PARTICULAR PURPOSE ARE
DISCLAIMED. IN NO EVENT SHALL THE COPYRIGHT OWNER OR CONTRIBUTORS BE LIABLE FOR
ANY DIRECT, INDIRECT, INCIDENTAL, SPECIAL, EXEMPLARY, OR CONSEQUENTIAL DAMAGES
(INCLUDING, BUT NOT LIMITED TO, PROCUREMENT OF SUBSTITUTE GOODS OR SERVICES;
LOSS OF USE, DATA, OR PROFITS; OR BUSINESS INTERRUPTION) HOWEVER CAUSED AND ON
ANY THEORY OF LIABILITY, WHETHER IN CONTRACT, STRICT LIABILITY, OR TORT
(INCLUDING NEGLIGENCE OR OTHERWISE) ARISING IN ANY WAY OUT OF THE USE OF THIS
SOFTWARE, EVEN IF ADVISED OF THE POSSIBILITY OF SUCH DAMAGE.

*/

/*

Script for starting pwr2 as daemon on boot (save as /etc/systemd/system/power.service):

[Unit]
Description="handle power"

[Service]
Type=forking
User=root
ExecStart=/home/osmc/pwr2 daemon

[Install]
WantedBy=default.target

---

Useful commands:

pwr2 on       - set ready pin to on (1), for testing
pwr2 off      - set ready pin to off (1), for testing
pwr2 shutdown - shutdown Pi, for testing
pwr2 daemon   - run as daemon, normal mode

systemctl enable power
systemctl start power
systemctl status power

*/

#include <stdio.h>
#include <stdlib.h>
#include <fcntl.h>

#include <sys/mman.h>
#include <sys/types.h>
#include <sys/stat.h>

#include <unistd.h>

#define BCM2708_PERI_BASE   0x3f000000
#define GPIO_BASE           (BCM2708_PERI_BASE + 0x200000)	// GPIO controller 

#define BLOCK_SIZE          (4*1024)

// IO Acces
struct bcm2835_peripheral {
	unsigned long addr_p;
	int mem_fd;
	void *map;
	volatile unsigned int *addr;
};

struct bcm2835_peripheral gpio = {GPIO_BASE};

extern struct bcm2835_peripheral gpio;  // They have to be found somewhere, but can't be in the header

// GPIO setup macros. Always use INP_GPIO(x) before using OUT_GPIO(x)

#define INP_GPIO(g) *(gpio.addr + ((g)/10)) &= ~(7<<(((g)%10)*3))
#define OUT_GPIO(g) *(gpio.addr + ((g)/10)) |=  (1<<(((g)%10)*3))

#define SET_GPIO_ALT(g,a) *(gpio.addr + (((g)/10))) |= (((a)<=3?(a) + 4:(a)==4?3:2)<<(((g)%10)*3))

#define GPIO_SET *(gpio.addr + 7)  // sets   bits which are 1 ignores bits which are 0
#define GPIO_CLR *(gpio.addr + 10) // clears bits which are 1 ignores bits which are 0

#define GPIO_READ(g)  *(gpio.addr + 13) &= (1<<(g))

// Exposes the physical address defined in the passed structure using mmap on /dev/mem
int map_peripheral(struct bcm2835_peripheral *p)
{
	// Open /dev/mem
	if ((p->mem_fd = open("/dev/mem", O_RDWR|O_SYNC) ) < 0) {
		printf("Failed to open /dev/mem, try checking permissions.\n");
		return -1;
	}
 
	p->map = mmap(
		NULL,
		BLOCK_SIZE,
		PROT_READ|PROT_WRITE,
		MAP_SHARED,
		p->mem_fd,      // File descriptor to physical memory virtual file '/dev/mem'
		p->addr_p       // Address in physical map that we want this memory block to expose
	);

	if (p->map == MAP_FAILED) {
		perror("mmap");
		return -1;
	}

	p->addr = (volatile unsigned int *)p->map;

	return 0;
}

void unmap_peripheral(struct bcm2835_peripheral *p) {
	munmap(p->map, BLOCK_SIZE);
	close(p->mem_fd);
}

#define readyPin 2
#define shutdownPin 3

int main(int argc, char **argv) {

	if(map_peripheral(&gpio) == -1) {
		printf("Failed to map the physical GPIO registers into the virtual memory space.\n");
		return -1;
	}

//R1:0/R2:2 SDA - 3
//R1:1/R2:3 SCL - 5

	INP_GPIO(readyPin);
	OUT_GPIO(readyPin);
	INP_GPIO(shutdownPin); 

	if(argc == 2) {

		if(strcmp(argv[1], "off") == 0)
			GPIO_SET = 1 << readyPin;

		else if(strcmp(argv[1], "on") == 0)
			GPIO_CLR = 1 << readyPin;

		else if(strcmp(argv[1], "shutdown") == 0) {

			system("sudo systemctl stop mediacenter");
			sleep(4);
			system("sudo shutdown -h now");

		} else if(strcmp(argv[1], "wait") == 0) {

			GPIO_CLR = 1 << readyPin;

			while(argc) {
				argc = GPIO_READ(shutdownPin);
				usleep(250000); // 250 ms
			}
			argc = 0;
			system("sudo systemctl stop mediacenter");
			sleep(4);
			system("sudo shutdown -h now");

		} else if(strcmp(argv[1], "daemon") == 0) {

			pid_t pid, sid;

			pid = fork();

			if(pid < 0)
                exit(1);
			else if (pid > 0)
                exit(0);

			umask(0);

			sid = setsid();

			if(sid < 0)
				exit(2);

			close(STDIN_FILENO);
			close(STDOUT_FILENO);
			close(STDERR_FILENO);
		
			GPIO_CLR = 1 << readyPin;

			while(argc) {
				argc = GPIO_READ(shutdownPin);
				usleep(200000); // 200 ms
			}

			argc = 0;
			system("sudo systemctl stop mediacenter");
			sleep(4);
			system("sudo shutdown -h now");
		}
	
	}

	return 0;

}

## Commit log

2017-09-18 Initial commit of first part of design
    [PSU.sch, PowerSwitch.kicad_pcb, PowerSwitch.sch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]
2017-09-19 Added code for Raspberry Pi power handling
    A Raspberry Pi daemon for power handling, to be used together with the
    power switch.
2017-09-19 Added PowerSwitch firmware
2017-09-20 Added reference to pre-amp board firmware, moved power switch firmwre
2017-09-20 Added controller schematics and PCB
    [controller.kicad_pcb, controller.sch]
